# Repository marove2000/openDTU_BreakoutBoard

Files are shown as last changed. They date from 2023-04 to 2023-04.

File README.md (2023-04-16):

# OpenDTU Breakout Board

This is a fully comaptible Breakout Board for the [OpenDTU](https://github.com/tbnobody/OpenDTU/) Project. With the opendtu breakout board and the opendtu software, you can read out, control and process Hoymiles inverters. In addition, the current energy yield is shown directly on a display.

This PCB has been designed together with the developers and is fully compatible. New features will of course always be added immediately ;).

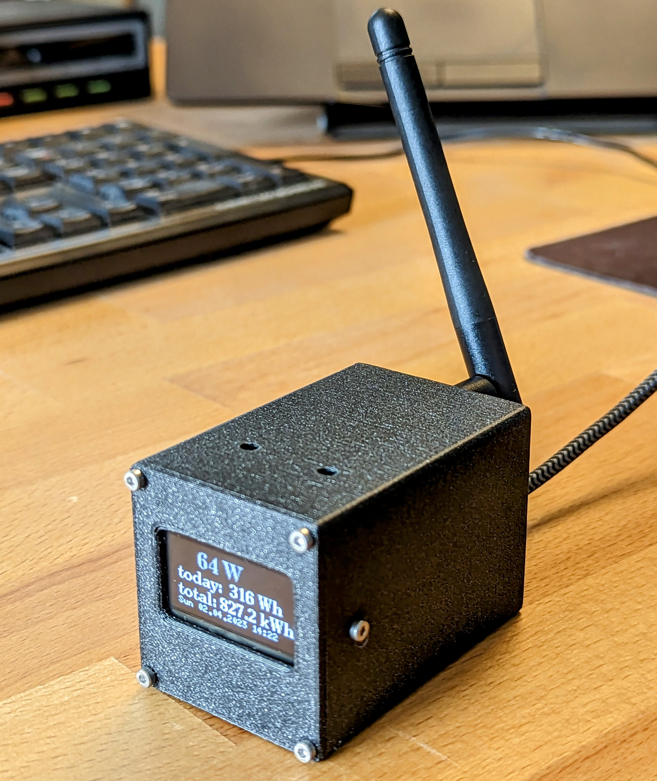
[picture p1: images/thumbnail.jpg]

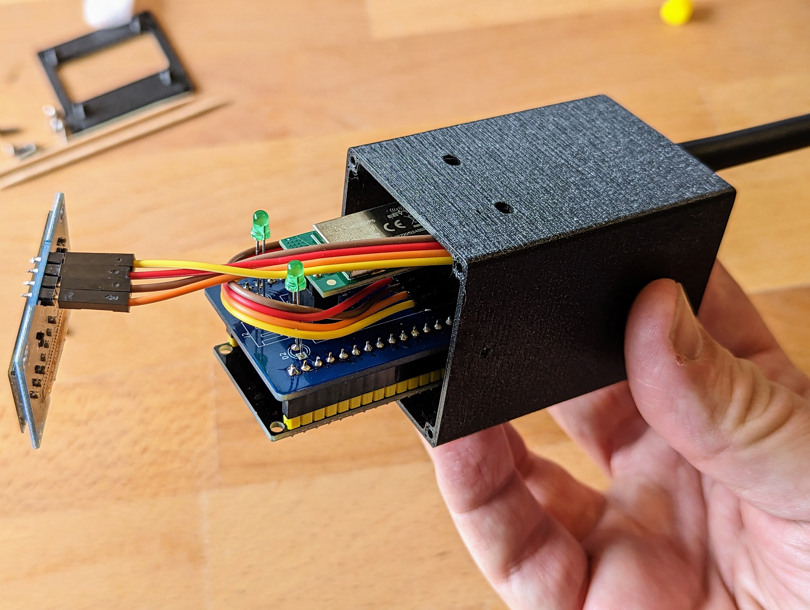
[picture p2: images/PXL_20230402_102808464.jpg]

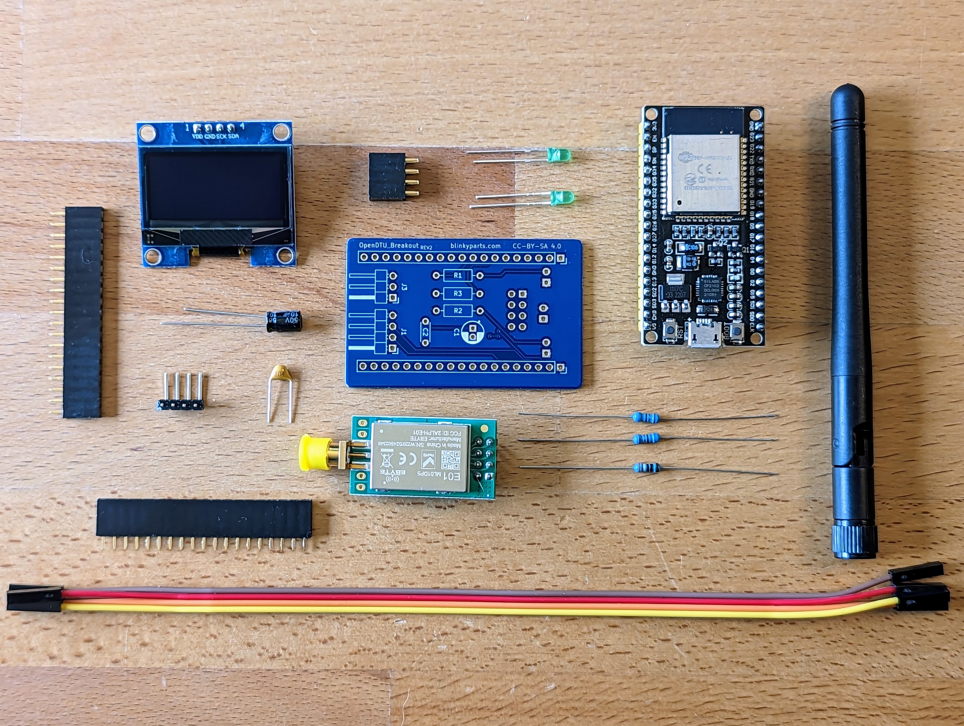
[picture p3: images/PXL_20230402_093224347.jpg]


### Parts List

| Quantity | Name | Description | Label/Color Code |
|---|---|---|---|
| 1 | U1 | ESP32 | ESP32-WROOM32 |
| 1 | U2 | Wireless module | ML01DP5 |
| 2 | D1,D2 | 3mm green LED | |
| 1 | C1 | 10µF capacitor | |
| 2 | C2 | 100nF ceramic capacitor | 104 |
| 1 | J1 | 4x L-shaped pin header | |
| 2 | U1 | 1x19 pin female header | |
| 1 | | 4-way cable | |
| 1 | R1,R2 | 68Ω resistor |  |
| 1 | R3 | 390Ω resistor |  |
| 1 | | PCB (Printed Circuit Board) | |
| 6 | | Optional: M2x6 screw | |
| 2 | | Optional: 3D-printed case parts | |
| 2 | | Not included: Toothpick | |
| 1 | | Not included: Micro-USB cable | |

### Purchase a Soldering Kit

If you don't want to source the PCBs and components yourself, you can also buy a soldering kit directly from the online shop at blinkyparts.com: [https://shop.blinkyparts.com/de/OpenDTU-Breakoutboard-Dein-Auswertung-fuer-deine-Balkonsolaranlage/blink237542](https://shop.blinkyparts.com/de/OpenDTU-Breakoutboard-Dein-Auswertung-fuer-deine-Balkonsolaranlage/blink237542)

### Manual
You can find the manual and pictures of every build step here: [https://github.com/Binary-Kitchen/SolderingTutorial/tree/master/OpenDTU_Breakout](https://github.com/Binary-Kitchen/SolderingTutorial/tree/master/OpenDTU_Breakout)

## Case

You cand find the Case here: [https://www.printables.com/de/model/441037-opendtu-breakoutboard-case](https://www.printables.com/de/model/441037-opendtu-breakoutboard-case)

### Copyright and Authorship

- Board: [CC-BY-NC-SA 4.0](https://creativecommons.org/licenses/by-nc-sa/4.0/) - Noby, Jan and Timo @ [blinkyparts.com](https://shop.blinkyparts.com)
- Code: [GPLv2](https://www.gnu.org/licenses/old-licenses/gpl-2.0.html) - [tbnobody](https://github.com/tbnobody/OpenDTU)
- Manual (TeX): [LPPL](https://www.latex-project.org/lppl.txt) - [Marei Peischl](https://peitex.de)
- Manual (pdf): [CC-BY-SA 4.0](https://creativecommons.org/licenses/by-sa/4.0/) - [Binary Kitchen e.V.](https://www.binary-kitchen.de)

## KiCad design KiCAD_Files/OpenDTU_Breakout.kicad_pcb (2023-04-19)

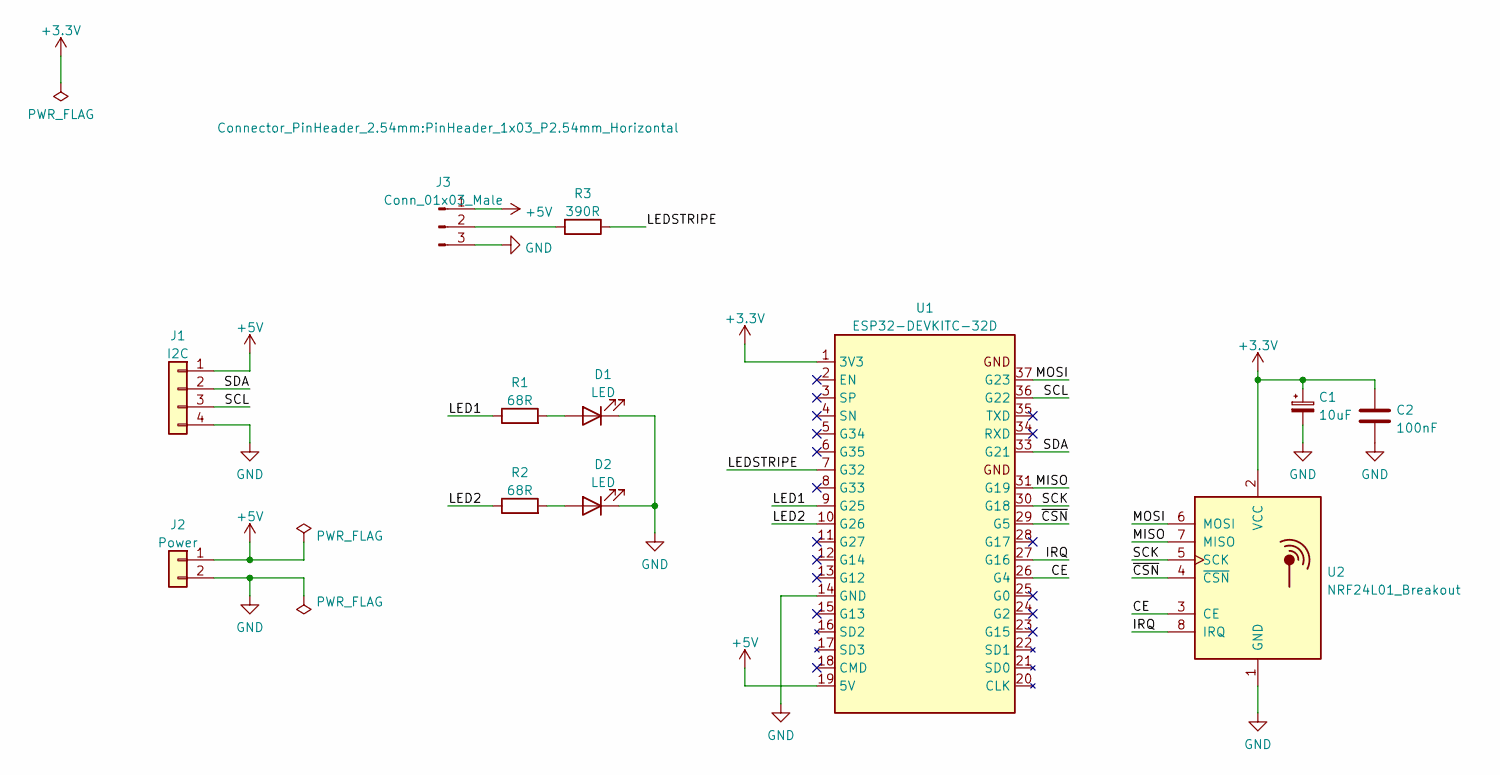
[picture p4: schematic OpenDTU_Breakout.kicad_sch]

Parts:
C1: 10uF; CP_Radial_D5.0mm_P2.00mm
C2: 100nF; C_Disc_D4.3mm_W1.9mm_P5.00mm
D1, D2: LED; LED_D3.0mm
J1: I2C; PinHeader_1x04_P2.54mm_Horizontal
J2: Power; JST_EH_S2B-EH_1x02_P2.50mm_Horizontal
J3: Conn_01x03_Male; PinHeader_1x03_P2.54mm_Horizontal
R1, R2: 68R; R_Axial_DIN0207_L6.3mm_D2.5mm_P10.16mm_Horizontal
R3: 390R; R_Axial_DIN0207_L6.3mm_D2.5mm_P10.16mm_Horizontal
U1: ESP32-DEVKITC-32D; ESP32-NodeMCU_WROOM_32; PARTREV 4
U2: NRF24L01_Breakout; nRF24L01+PA+LNA_Breakout

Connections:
+3.3V: C1.1, C2.1, U1.1 (3V3), U2.2 (VCC)
+5V: J1.1, J2.1, J3.1, U1.19 (5V)
/CE: U1.26 (G4), U2.3 (CE)
/IRQ: U1.27 (G16), U2.8 (IRQ)
/LED1: R1.1, U1.9 (G25)
/LED2: R2.1, U1.10 (G26)
/LEDSTRIPE: R3.1, U1.7 (G32)
/MISO: U1.31 (G19), U2.7 (MISO)
/MOSI: U1.37 (G23), U2.6 (MOSI)
/SCK: U1.30 (G18), U2.5 (SCK)
/SCL: J1.3, U1.36 (G22)
/SDA: J1.2, U1.33 (G21)
/~CSN: U1.29 (G5), U2.4 (~CSN)
GND: C1.2, C2.2, D1.1 (K), D2.1 (K), J1.4, J2.2, J3.3, U1.14 (GND), U1.32 (GND), U1.38 (GND), U2.1 (GND)
unnamed: D1.2 (A), R1.2
unnamed: D2.2 (A), R2.2
unnamed: J3.2, R3.2

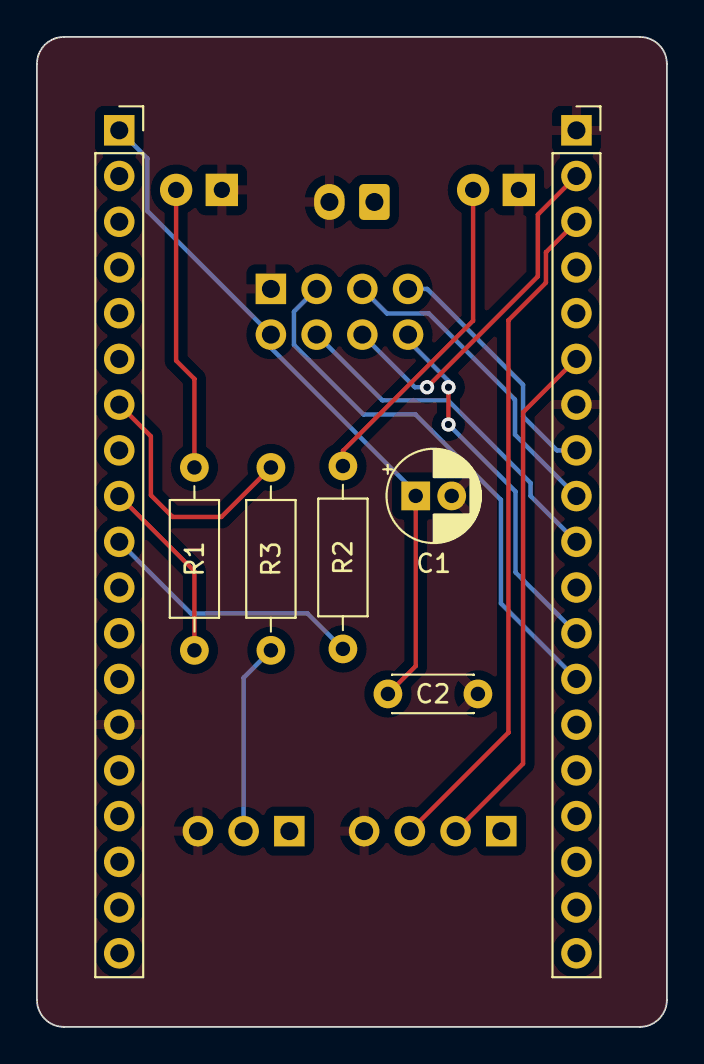
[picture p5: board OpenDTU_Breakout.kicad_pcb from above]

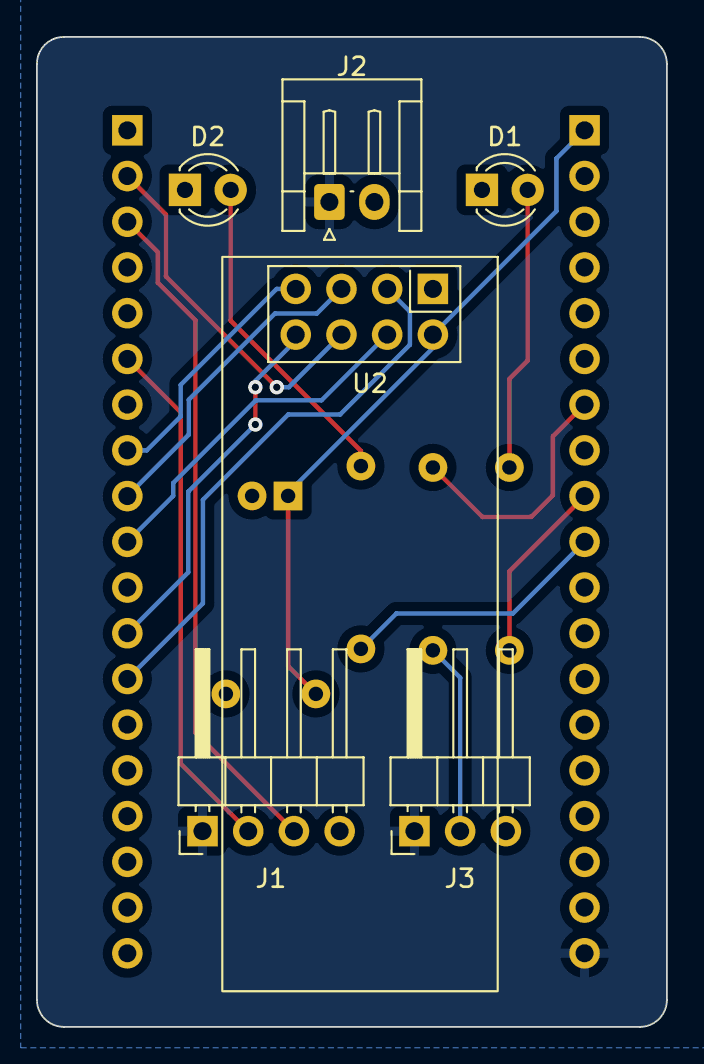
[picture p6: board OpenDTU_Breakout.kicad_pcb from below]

Board: 2 copper layers, 35.0 x 55.0 mm, 12 parts (6 on the bottom side), 17 nets.

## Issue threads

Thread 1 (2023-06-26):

Feedback

pkese, 2023-06-26:
This is not an issue.

I just got the kit from https://shop.blinkyparts.com/en/OpenDTU-Your-evaluation-for-your-balcony-solar-system/blink237542 and would like to share some thoughts.

The kit is wonderful and easy to assemble. I especially appreciate how cool and smart the 3d printed case is.

The few nuisances I encountered were:

- I misplaced the wires bonding the breakout board and OLED display, because they are not placed in the same order on both connectors. Luckily I didn't destroy anything - it worked after I reconnected the wires correctly. It would be nice if at least the silk-screen on the breakout board would provide the names for each wire as does the OLED board. Same ordering on both connectors would be even better.

- The LEDs are extremely bright. I think the resistors could be a little bit bigger.
  In the kit it would be nice if LEDs were of different color (e.g. one green, one yellow like the sun).

- I couldn't find out which type of ESP32 chip is on the module so now I don't know if I should flash `opendtu-generic_esp32.bin`, `
opendtu-generic_esp32s3.bin` or `opendtu-generic_esp32s3_usb.bin`.

Otherwise I'm extremely happy with the board.

Feel free to close this ticket. Thanks.

marove2000, 2023-06-27:
Hi @pkese

this is very good feedback! I'm glad you've liked the soldering kit.

For the next Review I will take your suggestions in account and try to fix the most issues! About the generic_esp32.bin: I will add this in the description. This is pretty new.

About the LEDs: Yes the LEDs are very bright. I will also take this into the next review of the PCB. Different colours are more complicated and the people can be confused about where to add them. I would prefer same colour. Also yellow or red are indicating errors. Green is more friendly ;)

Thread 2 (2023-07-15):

SH1106 Black display

perretju, 2023-07-15:
Hello,

I just got the kit from https://shop.blinkyparts.com/en/OpenDTU-Your-evaluation-for-your-balcony-solar-system/blink237542 (nrf module). The kit is wonderful and easy to assemble (thanks for the manual :-))

I've soldered the various components together and Opendtu works with the 2 green LEDs. However, the SH1106 screen remains black.
I have no voltage between the VCC terminal and GND (3.3V ?). Is this normal?

Reading the printed circuit, I don't understand how we can have the 3.3 V. Can you help please ?

Thank you for advance,

Jul

marove2000, 2023-07-17:
Hi Jul,

thanks for your feedback. Check the components: You can also operate the components individually and connect them directly to the ESP32: Grab some cables and have a look at https://github.com/tbnobody/OpenDTU where you will find the instructions on how to connect the radio module directly to the ESP. The display must be connected as follows:

VDD (display) <-> V5 or 5V (ESP32)
GND (display) <-> GND (ESP32)
SCK/SCL (display) <-> G22 (ESP32)
SDA (display) <-> G21 (ESP32)

If it works then, the fault is probably on the board. Please check your solder connections. Contact us if you need spare parts.

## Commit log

2023-04-16 initial kicad commit
    [OpenDTU_Breakout-B_Cu.gbr, OpenDTU_Breakout-B_Mask.gbr, OpenDTU_Breakout-B_Paste.gbr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]
2023-04-16 added gerber files for REV2
2023-04-16 added case to readme
2023-04-19 flipped and rotated J1 and J3
    [OpenDTU_Breakout.kicad_pcb]
2023-04-19 generated new gerber files for REV3
    [OpenDTU_Breakout-B_Cu.gbr, OpenDTU_Breakout-B_Mask.gbr, OpenDTU_Breakout-B_Paste.gbr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]
